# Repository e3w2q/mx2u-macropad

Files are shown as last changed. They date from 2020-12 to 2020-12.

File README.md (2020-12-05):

# MX2U!




Happy Holidays Macro Pad.

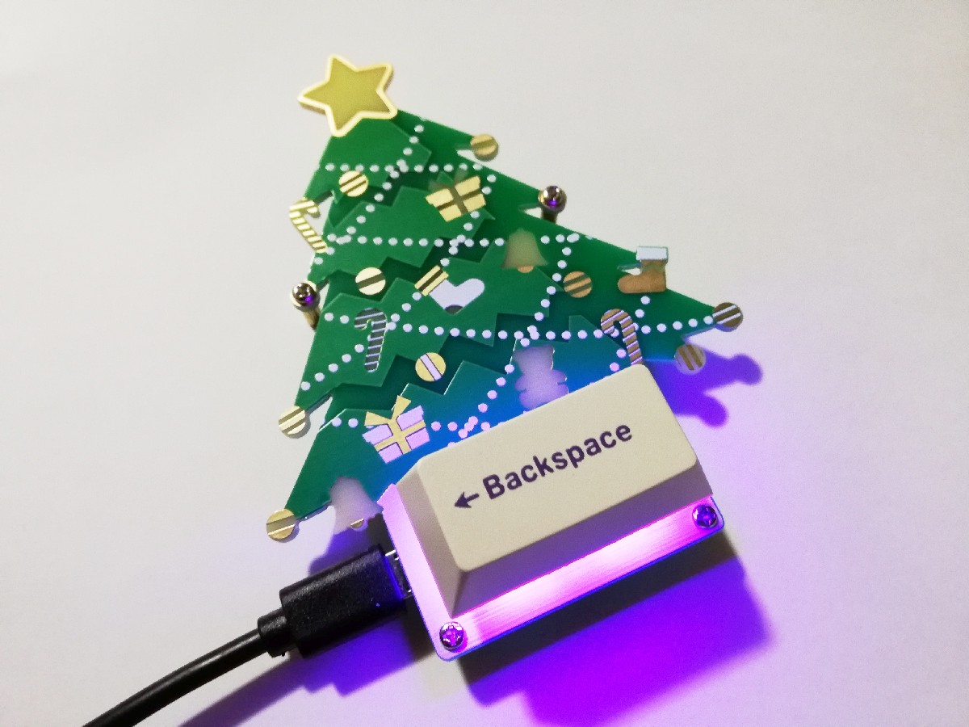
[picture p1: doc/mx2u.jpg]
mx2u


## What is the MX2U! ?

MX2U! is a macro pad for MX switches that can be used for fun at certain times of the year.

You can place a single 2U key or two 1U keys on this macro pad.

Note: When using the 2U key, the backlight goes directly into your eyes!

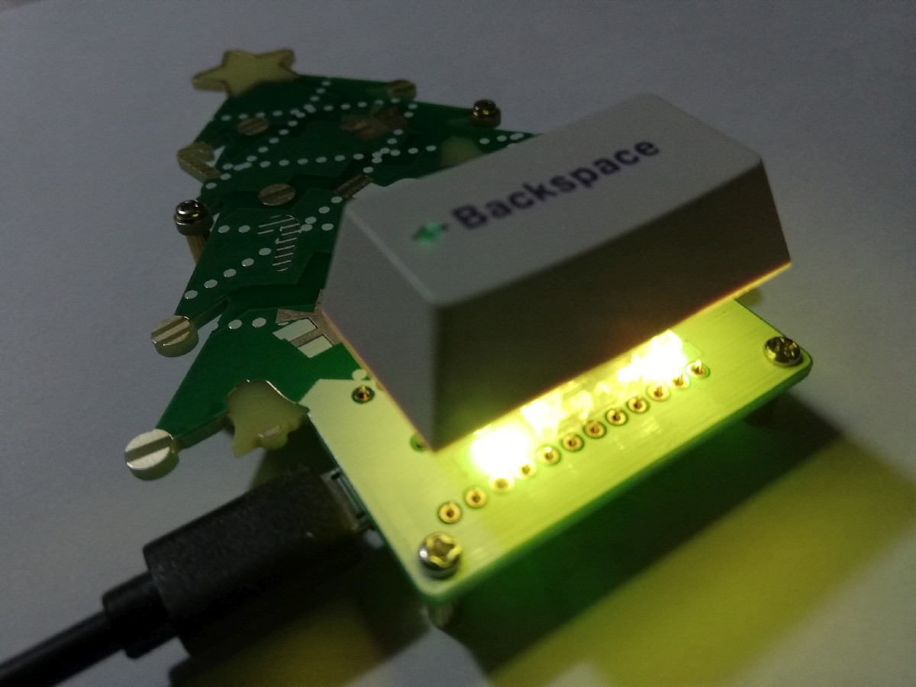
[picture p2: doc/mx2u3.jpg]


## Link

[Hardware data (PCB)](pcb/)

[Firmware](https://github.com/e3w2q/qmk_firmware/tree/e3w2q/keyboards/e3w2q/mx2u)

[PCBの入手方法](doc/pcb_order_guide_jp.md)

[パーツリスト](doc/bom_list_jp.md)

[ビルドガイド](doc/readme_jp.md)

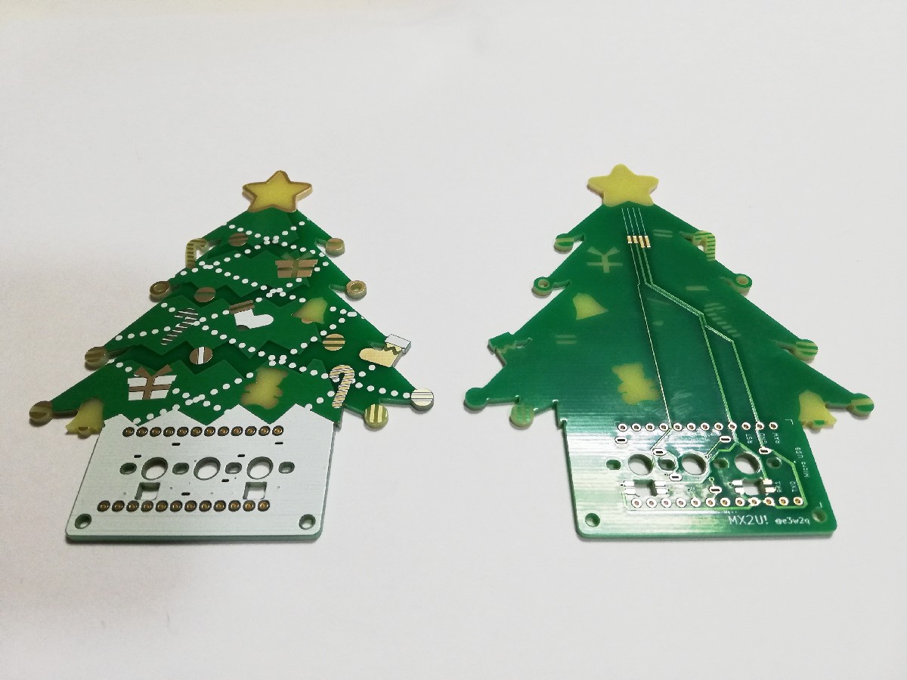
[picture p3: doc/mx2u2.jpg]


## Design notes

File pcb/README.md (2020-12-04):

# MX2U! PCB Data

## Schematic
[Schematic PDF](../doc/ukiha.pdf?raw=true)
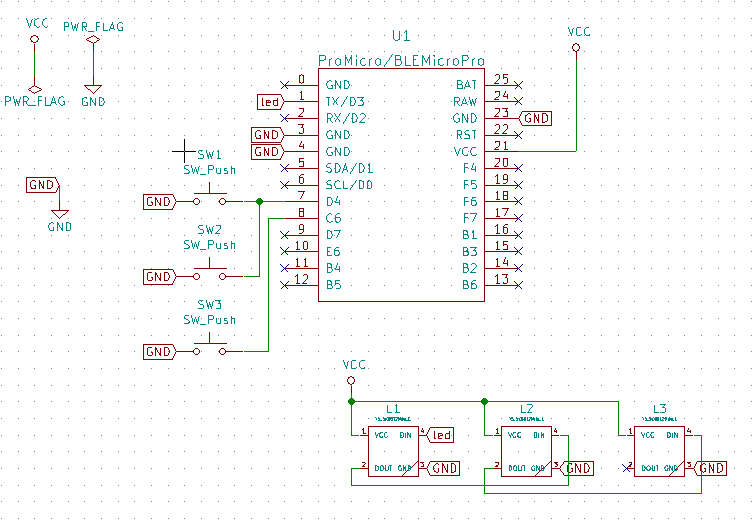
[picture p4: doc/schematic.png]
Schematic


## PCB Layout
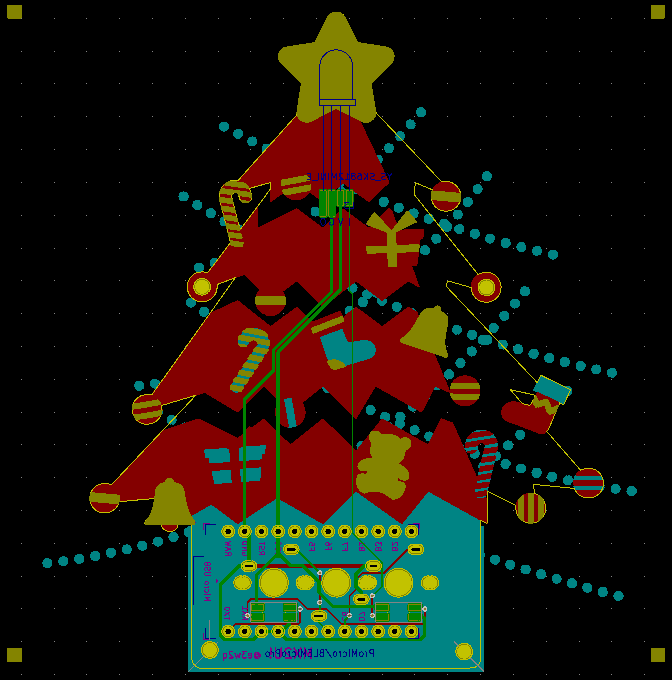
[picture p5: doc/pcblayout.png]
PCB Layout


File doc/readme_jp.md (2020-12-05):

# MX2U! ビルドガイド

<!-- TOC -->

- [MX2U! ビルドガイド](#mx2u-ビルドガイド)
    - [必要なパーツ](#必要なパーツ)
    - [使用する道具、消耗品](#使用する道具消耗品)
    - [ビルドガイド](#ビルドガイド)
        - [Pro Microのもげ防止加工](#pro-microのもげ防止加工)
        - [はんだ付けのイメージトレーニング](#はんだ付けのイメージトレーニング)
        - [キースイッチ部分のLEDの取り付け](#キースイッチ部分のledの取り付け)
        - [ツリー部分のLEDの取り付け](#ツリー部分のledの取り付け)
        - [キースイッチの取り付け](#キースイッチの取り付け)
        - [Pro Microの取り付け](#pro-microの取り付け)
        - [スペーサーの取り付け](#スペーサーの取り付け)
        - [キーキャップの取り付け](#キーキャップの取り付け)
        - [ファームウェアの書き込み](#ファームウェアの書き込み)
        - [光るパターンを変える](#光るパターンを変える)

<!-- /TOC -->

## 必要なパーツ

[MX2U! パーツリスト](bom_list_jp.md)をご覧ください。

## 使用する道具、消耗品

[使用する道具、消耗品](tool_guide_jp.md)におすすめの道具類、注意事項等をまとめましたのでご覧ください。

## ビルドガイド

### Pro Microのもげ防止加工

Pro Microにエポキシ接着剤を盛って、簡単にはもげないようにします。

参考1:[ProMicroのモゲ防止ついでにQMK_Firmwareを書き込む - Qiita](https://qiita.com/hdbx/items/2f3e4ddfcadda2a5578e)
参考2:[もげ予防 - Self-Made Keyboards in Japan](https://scrapbox.io/self-made-kbds-ja/%E3%82%82%E3%81%92%E4%BA%88%E9%98%B2)

エポキシ接着剤の2液を混ぜます。

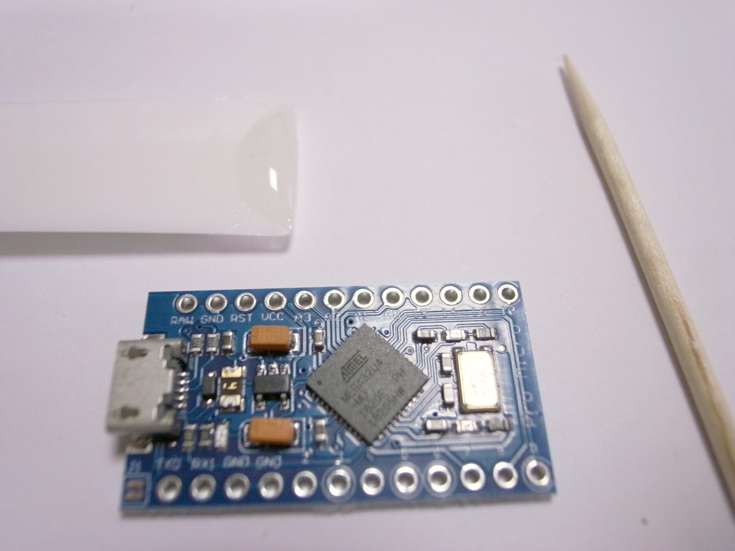
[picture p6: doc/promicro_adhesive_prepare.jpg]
adhesive_prepare


接着剤を付け始める前にMicro USBコネクタを横から見てください。側面に穴が開いています。この穴に接着剤が入ると端子が入らなくなったり、入りにくくなったりします。

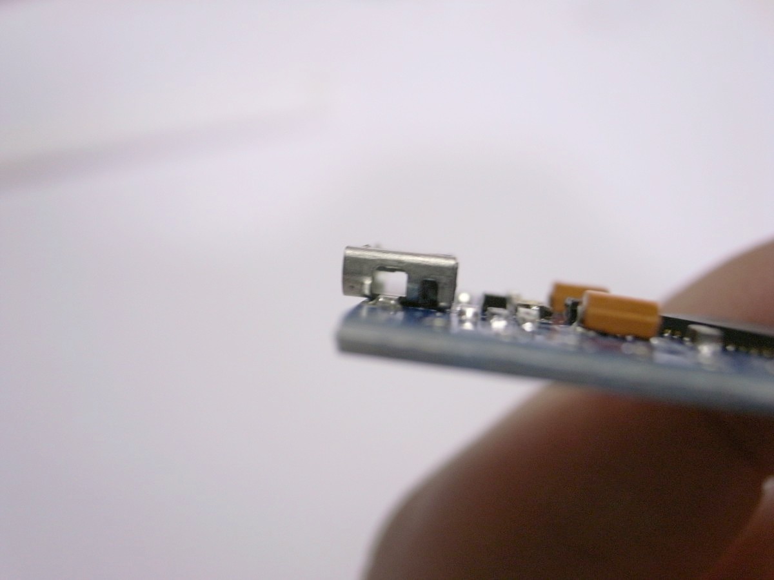
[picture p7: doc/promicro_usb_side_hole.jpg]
usb_side_hole


この穴を避けて、つまようじなどで接着剤を盛っていきます。

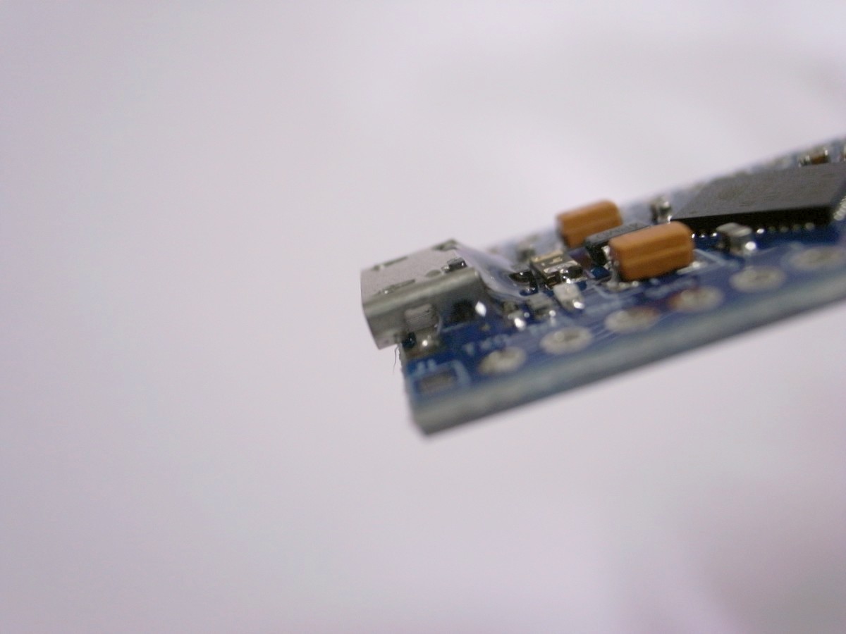
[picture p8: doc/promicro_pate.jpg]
promicro_pate


乾くまで置いておきます。

### はんだ付けのイメージトレーニング

はんだ付けに慣れている方は次の項に進んでください。

全くはんだ付けをしたことがなかったり、数年ぶりにはんだ付けをする場合は、以下の動画が参考になります。

- [はんだ付けの詳細.m2p - YouTube](https://www.youtube.com/watch?v=ZA-ehWjRfYM)

- [チップ抵抗のはんだ付けと、はんだ量の調整（体験用基板を使用） - YouTube](https://www.youtube.com/watch?v=vqKKElJ1vw0)

- [基礎からわかる！自キ入門講座 第8回「自作キーボードのつくりかた #2」 - YouTube](https://www.youtube.com/watch?v=LOC53FeU-QM&t=999)

### キースイッチ部分のLEDの取り付け

**基板裏側**にLEDを取り付けます。

ツリーが描いてある側が基板の表で、反対側が裏です。画像は右側が裏です。

mx2u2

YS-SK6812MINI-Eを取り付けます。向きは写真のように欠けているタブが左下に向くようにして開口部に置き、はんだ付けしてください。

高い温度ではんだ付けを行うと破損の可能性がありますので、温調機能付きはんだごてで270～320度程度に設定してはんだ付けしてください。

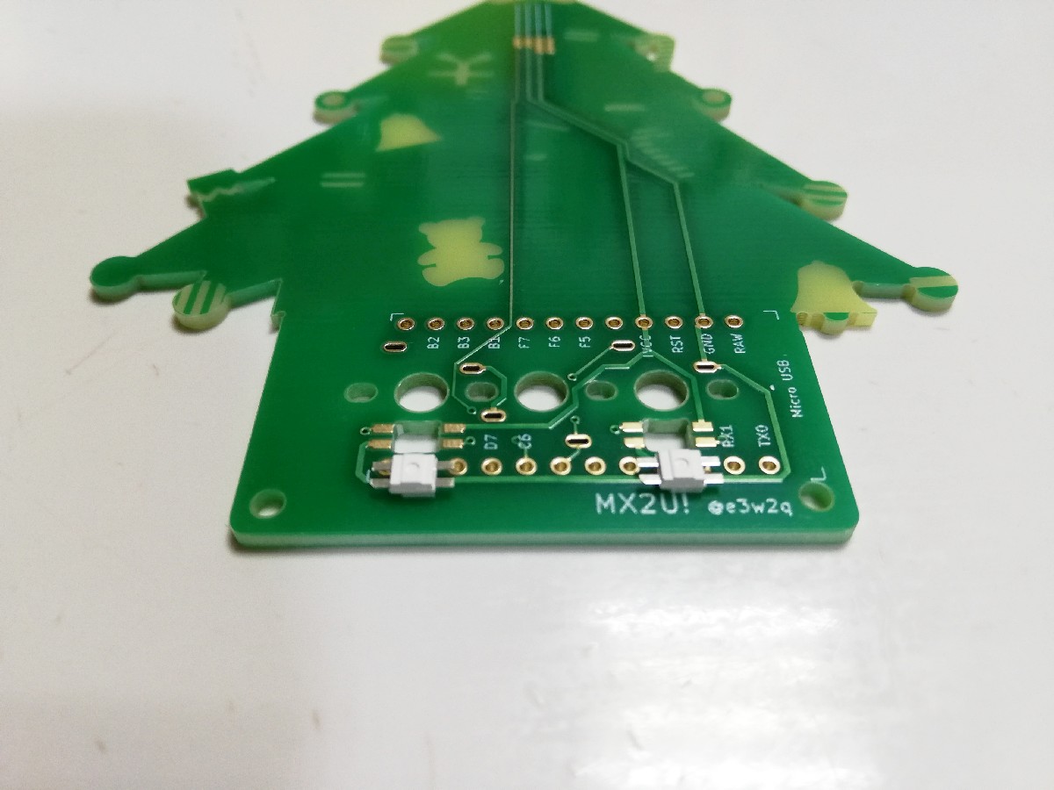
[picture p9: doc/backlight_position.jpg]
backlight_position


### ツリー部分のLEDの取り付け

**この項はまだ未検証です**。

ツリー部分の裏側に、スルーホールタイプのシリアルLED（WS2812）を取り付けます。

裏側から見て左から、Data in(DIN)、電源(VCC)、Ground(GND)、Data out(DOUT)となるように配置します。

はんだ付けしやすいように足をあらかじめ曲げておき、テープ等で固定するとやりやすいです。

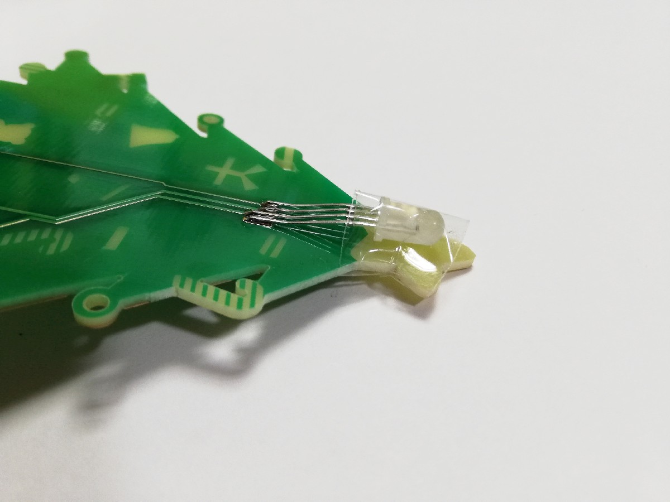
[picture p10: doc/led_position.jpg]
led_position


### キースイッチの取り付け

2Uのキーキャップを使う場合は真ん中に1個、1Uのキーキャップを使う場合は2個、表側から差し込みます。キースイッチの足が曲がっている場合はまっすぐにしてから差し込んでください。

2Uキーキャップを使いたい場合は以下の注意点があります。

- バックライトを光らせるとキースイッチを透過せずにダイレクトに光が出るので、まぶしい
- スタビライザーは使用できない

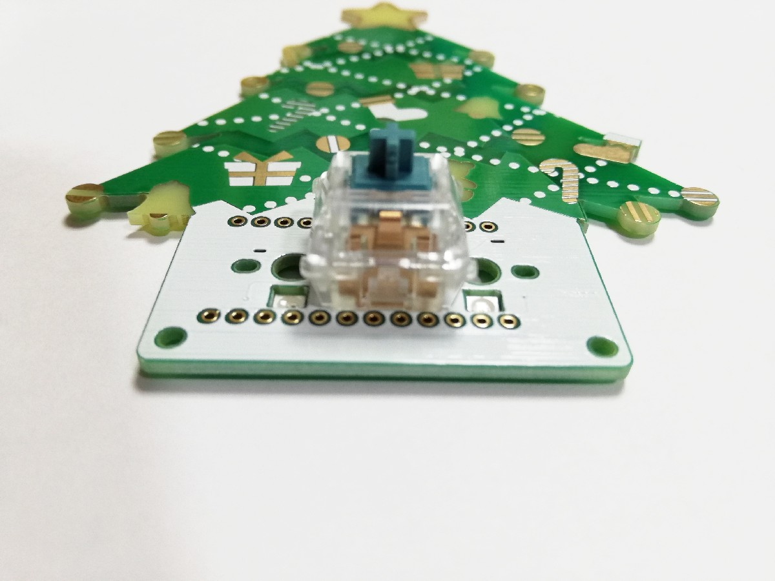
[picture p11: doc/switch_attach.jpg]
switch_attach


裏返します。

スイッチ2個の足がPro Microに干渉しないよう、はみ出した部分をニッパーでカットします。

ハンダ付けします。

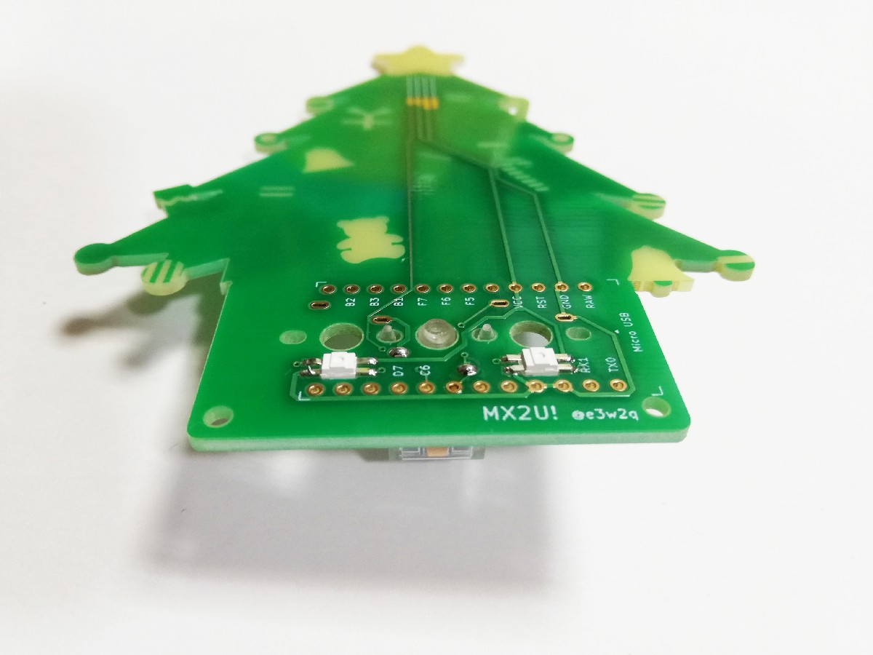
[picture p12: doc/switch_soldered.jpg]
switch_soldered


### Pro Microの取り付け

**基板裏側**のPro Micro設置部分のスルーホールに、コンスルーピンヘッダを根本まで差し込みます。

その際、

- コンスルーピンヘッダの金色の窓が遠い側を基板側とし、金色の窓が近い側をProMicro側とする
- 金色の窓の向きを揃える

ようにしてください。

参考: [Helixベータ ビルドガイド](https://github.com/MakotoKurauchi/helix/blob/master/Doc/buildguide_jp.md#pro-micro)

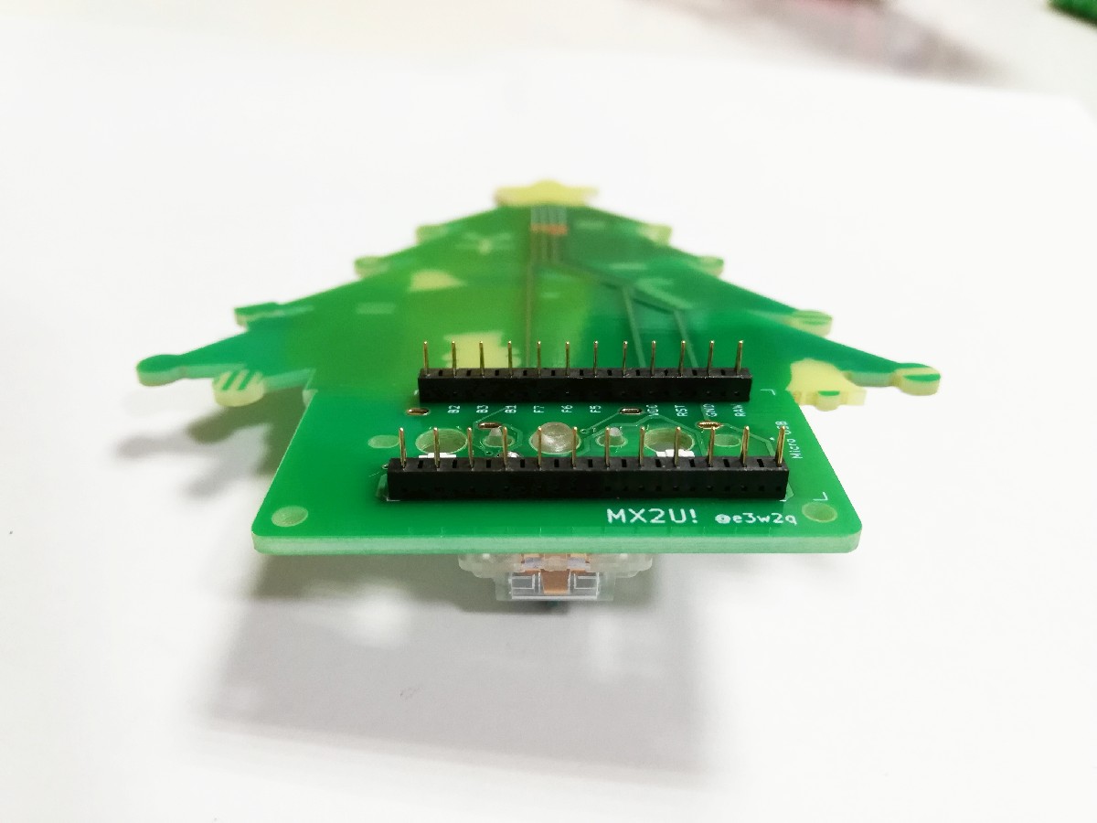
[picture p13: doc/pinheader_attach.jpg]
pinheader_attach


ピンヘッダにPro Microを差し込みます。**Pro Microの裏面（平らなほう）が上になるように、またマイクロUSBが基板端になるように**します。

**向きを間違えるとリカバリーが大変です。表裏、左右をよく確認してください。**

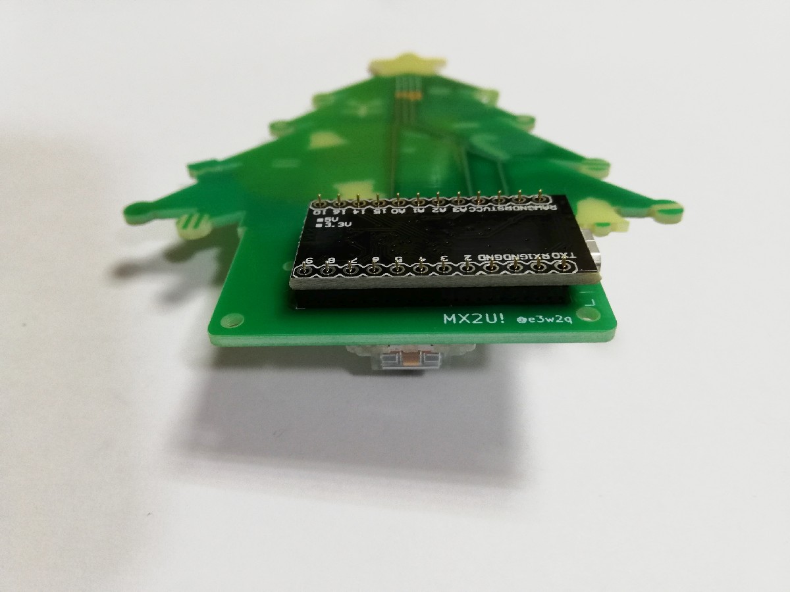
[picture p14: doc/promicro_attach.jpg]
promicro_attach


Pro Microとコンスルーピンヘッダをハンダ付けします。まず四隅をハンダ付けし、横から見てコンスルーピンヘッダとの間に隙間があれば押さえながらハンダを温めて浮かないようにします。そのあと、順番に全てハンダ付けします。

基板とコンスルーピンヘッダは接触しているため、ハンダ付けしません。

### スペーサーの取り付け

基板4箇所の穴に表側からM2ネジをはめ、裏側からスペーサーをねじ込みます。

### キーキャップの取り付け

キースイッチにキーキャップをはめます。

### ファームウェアの書き込み

以下のリンク先を参考にして、QMK Firmwareのビルド環境を用意します。

- Windows
  - [QMKビルド環境の構築(Windows Msys2編)](https://gist.github.com/e3w2q/4bc86e531d1c893d3d13af3e9895a94a)
- macOS
  - [セットアップ - QMK Firmware](https://docs.qmk.fm/#/ja/newbs_getting_started?id=macos)
- Linux
  - [セットアップ - QMK Firmware](https://docs.qmk.fm/#/ja/newbs_getting_started?id=linux)

構築中、

```
qmk setup
```

と入力する代わりに

```
qmk setup e3w2q/qmk_firmware --branch e3w2q
```

と入力してください。

または、`qmk setup`した後に、`C:\Users\USER_NAME\qmk_firmware\keyboards`配下に[https://github.com/e3w2q/qmk_firmware/tree/e3w2q/keyboards/e3w2q](https://github.com/e3w2q/qmk_firmware/tree/e3w2q/keyboards/e3w2q)以下をコピーしてもよいです。

用意されたキーマップを書き込むには以下を実行します。

```
qmk flash -kb e3w2q/mx2u -km default
```

`Detecting USB port, reset your controller now...`と表示されたらPro Microの`GND`と`RST`をピンセットやクリップなどで短絡させると書き込みが始まります。

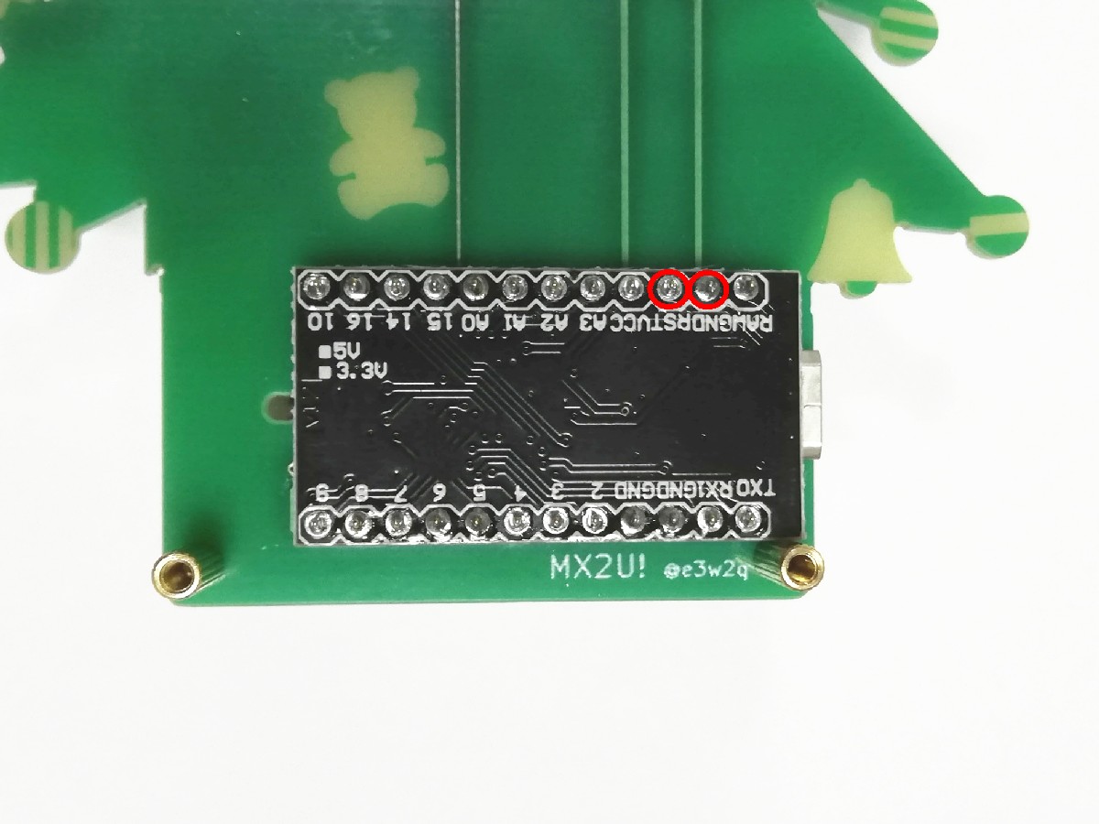
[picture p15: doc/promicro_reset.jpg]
promicro_reset


[QMK Configuratorのテストモード](https://config.qmk.fm/#/test)でキー入力が行えるかテストしてください。

### 光るパターンを変える

デフォルトのキーマップではGNDと以下のピンをピンセットやクリップなどで導通させることで、LEDの設定を変更できます。

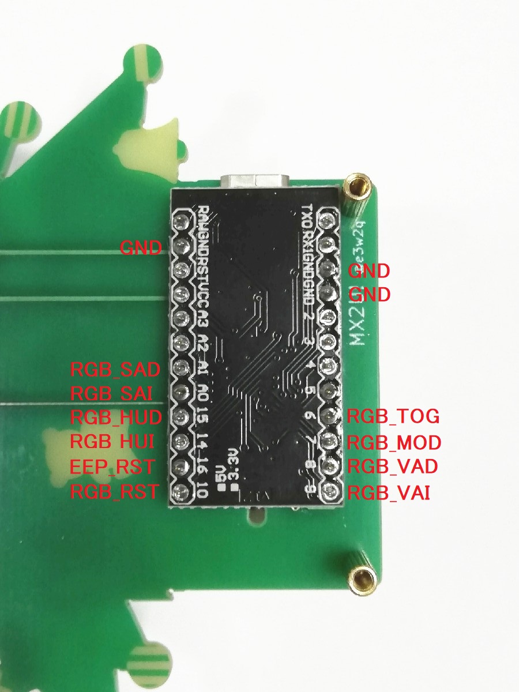
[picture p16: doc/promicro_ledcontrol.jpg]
promicro_ledcontrol


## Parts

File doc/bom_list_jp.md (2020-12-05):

# MX2U! パーツリスト

| 名前 | 数 | 備考 | 調達先の例 | 参考価格 |
| --- | --- | --- | --- | --- |
| MX2U! 基板 | 1枚 | [入手方法はこちら](pcb_order_guide_jp.md) | [Elecrow Online store](https://www.elecrow.com/) | 5枚で$31.70 |
| ★Pro Micro | 1個 | | https://talpkeyboard.stores.jp/items/5b24504ba6e6ee7ec60063e3 | 550円 |
| ★コンスルーピンヘッダ | 2個 | | https://talpkeyboard.stores.jp/items/5e056626d790db16e2889233 | 220円 |
| ★5ピン仕様のMX互換スイッチ または Kailh Mid-Heightスイッチ | 1個または2個 | | https://talpkeyboard.stores.jp/?category_id=59cf8860ed05e668db003f5d | 10個で450円～  |
| ★キーキャップ | 2U1個または1U2個 |  | https://talpkeyboard.stores.jp/items/5f5444c380933970d139e98c | 2個で150円など |
| M2スペーサー | 4個 | 8mm長程度 | https://ja.aliexpress.com/item/4000128244233.html | 50個で$0.74 |
| 鍋頭M2ネジ | 4個 | 3mm～5mm長程度 | https://ja.aliexpress.com/item/32865576659.html | 100個で$0.82 |
| M2ナット | 12個（4×12で使うなら10個） | |  |  |
| YS-SK6812MINI-E | 2個 |  | https://yushakobo.jp/shop/ys-sk6812mini-e/ | 10個で385円 |
| ★WS2812互換のスルーホールタイプのシリアルLED | 1個 | 動作未検証 | スイッチサイエンスのNeoPixel スルーホールLEDはWS2811のため不適合 |  |
| ★Micro USBケーブル | 1本 | 通信ができるもの | ダイソー | 110円 |

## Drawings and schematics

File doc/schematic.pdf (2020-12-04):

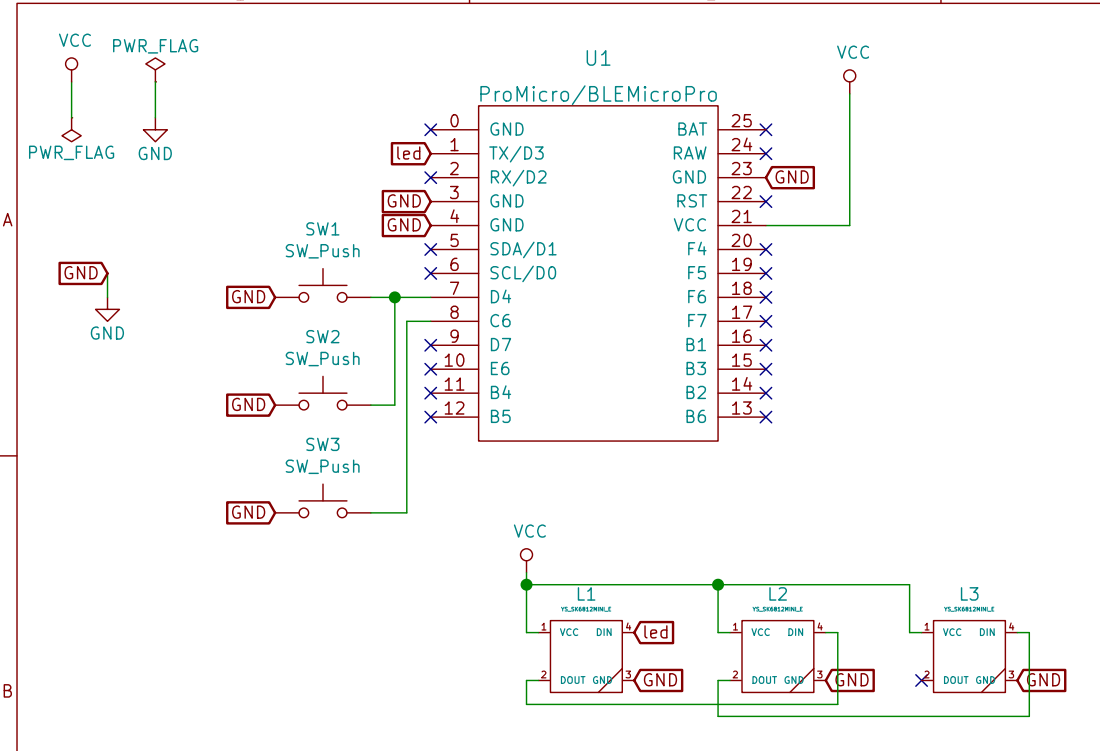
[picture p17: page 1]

led GND GND GND GND GND
SW1 SW_Push SW2 SW_Push SW3 SW_Push

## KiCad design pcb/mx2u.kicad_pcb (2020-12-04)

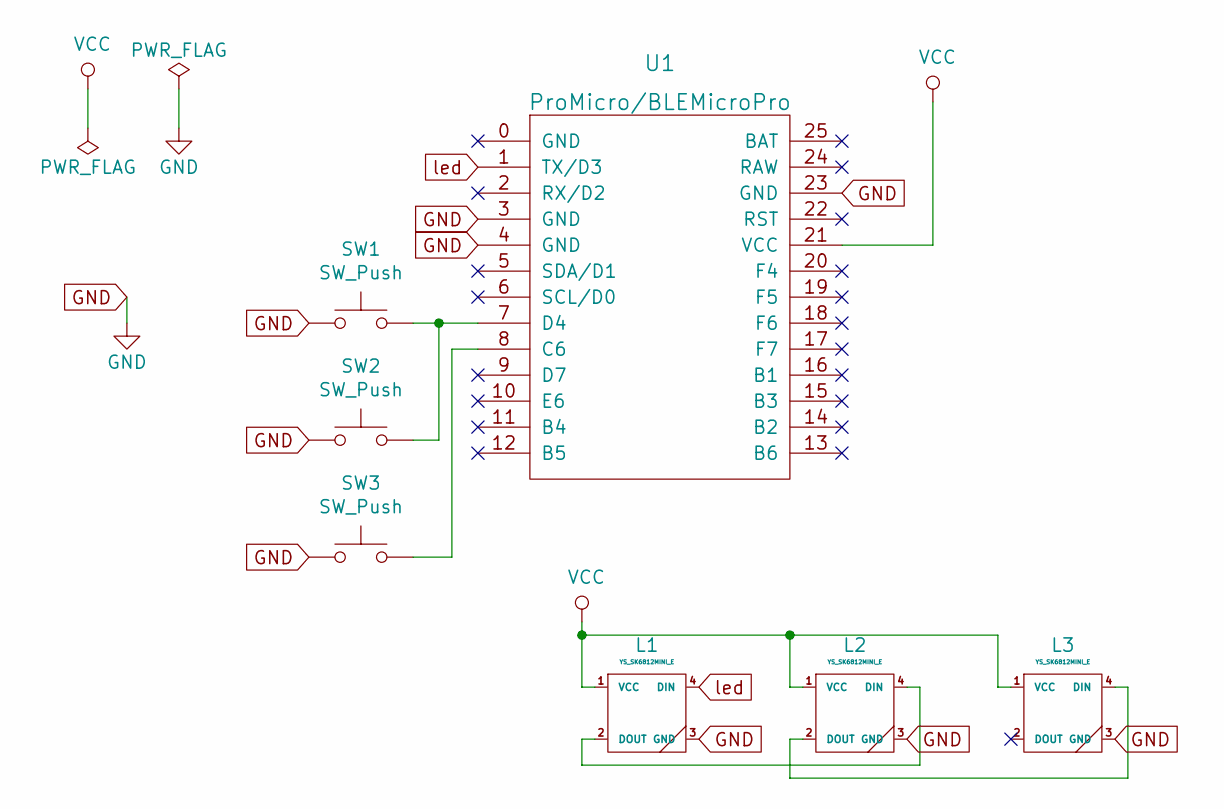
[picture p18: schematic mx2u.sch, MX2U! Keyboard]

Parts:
L1, L2: YS_SK6812MINI_E; YS-SK6812MINI-E
L3: YS_SK6812MINI_E; NeoPixcel_Diffused_5mm_Through_Hole_LED
SW1, SW2, SW3: SW_Push; CherryMX_MidHeight
U1: ProMicro/BLEMicroPro; ArduinoProMicro_ConThrough

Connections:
GND: L1.3 (GND), L2.3 (GND), L3.3 (GND), SW1.1, SW2.1, SW3.1, U1.3 (GND), U1.4 (GND), U1.23 (GND)
unnamed: L1.2 (DOUT), L2.4 (DIN)
unnamed: L2.2 (DOUT), L3.4 (DIN)
unnamed: SW1.2, SW2.2, U1.7 (D4)
unnamed: SW3.2, U1.8 (C6)
VCC: L1.1 (VCC), L2.1 (VCC), L3.1 (VCC), U1.21 (VCC)
led: L1.4 (DIN), U1.1 (TX/D3)

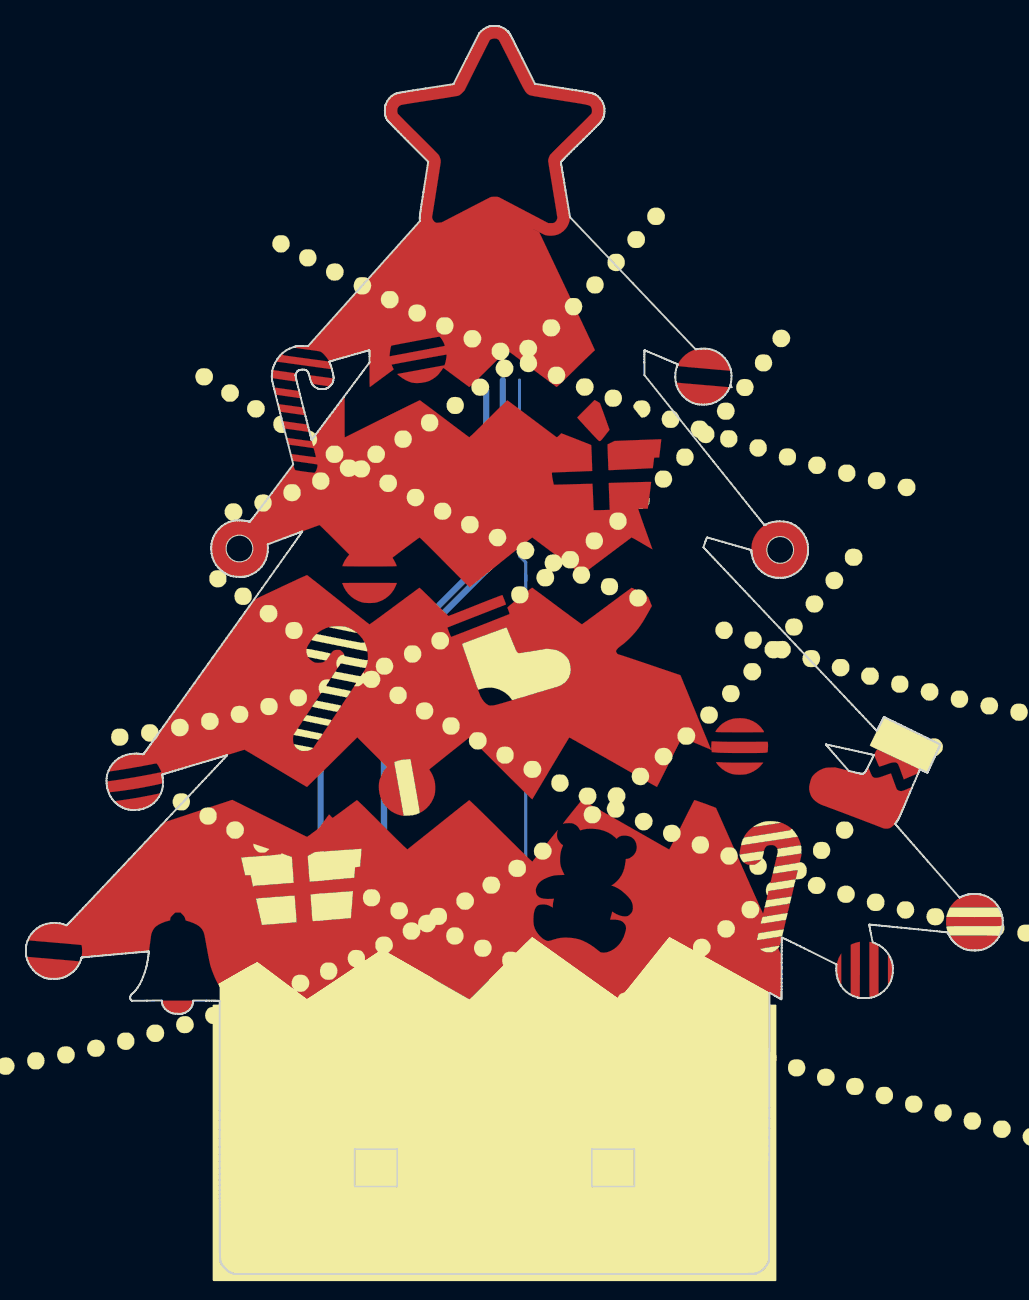
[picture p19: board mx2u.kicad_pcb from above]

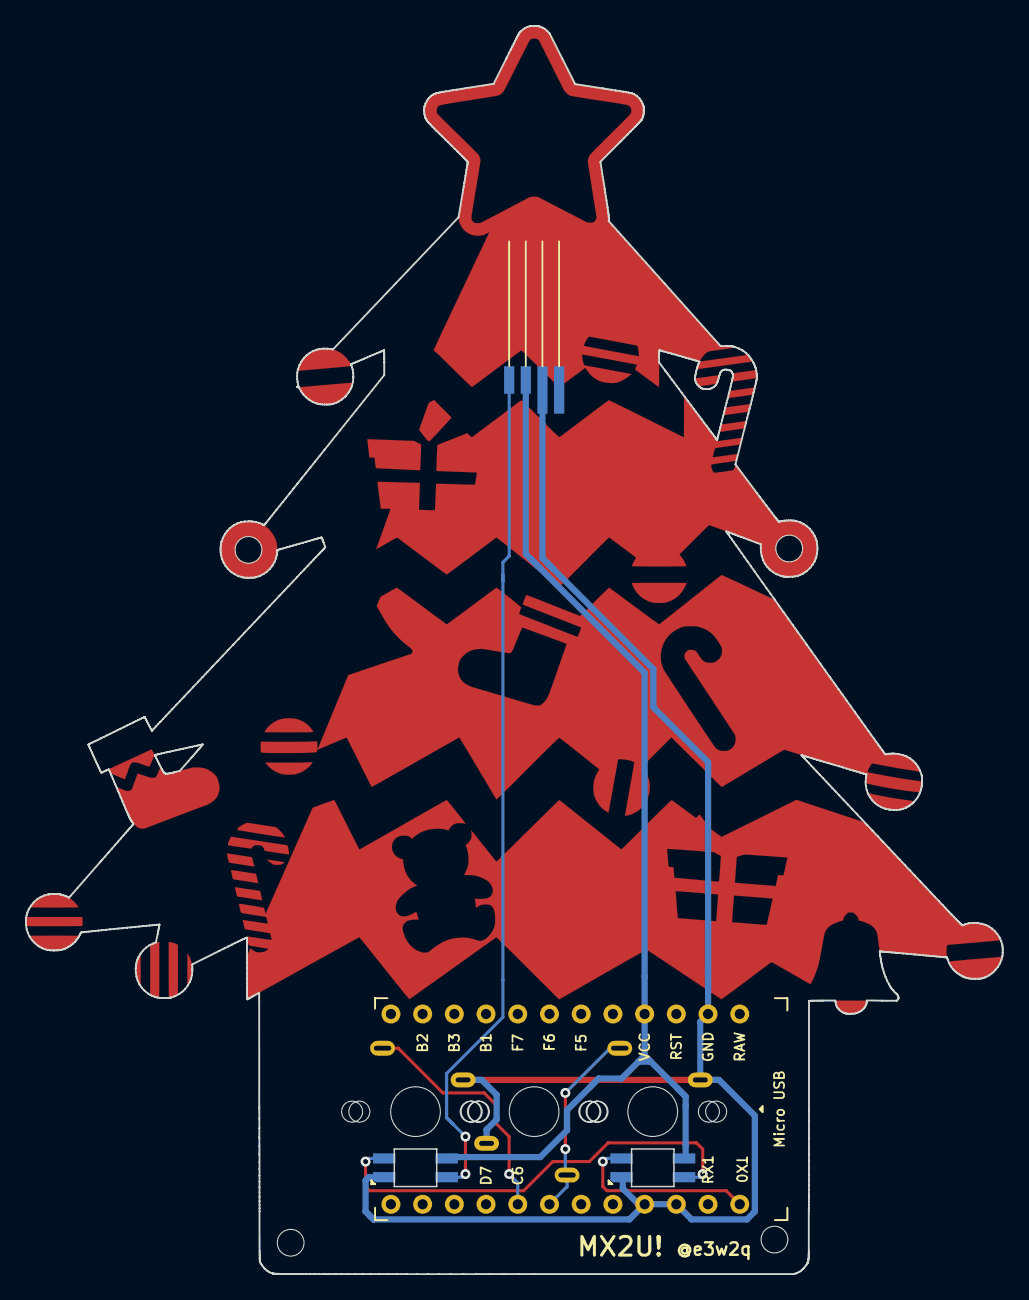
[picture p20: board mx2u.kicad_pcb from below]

Board: 2 copper layers, 78.2 x 100.0 mm, 7 parts (2 on the bottom side), 7 nets.

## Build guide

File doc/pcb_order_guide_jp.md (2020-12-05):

# PCBの入手方法

## ELECROWへ発注する場合

[ELECROW基板製造サービス](https://www.elecrow.com/pcb-manufacturing.html)から注文します。

アップロードするガーバーファイルは以下のものを使ってください。

| 概要 | URL | 寸法 |
| ---- | --- | --- |
| 基板 | https://github.com/e3w2q/mx2u-macropad/blob/main/pcb/mx2u-gerber.zip?raw=true | 100×78mm |

PCB ColorはデフォルトのGreenを選択してください。

Surface FinishはImmersion goldを選択するとメッキが金色になるのでおすすめです。

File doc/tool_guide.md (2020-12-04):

[English](tool_guide.md) / [日本語](tool_guide_jp.md)

# Tools and consumables

## Examples of procured products

This is a list of items that should be procured. The commentary is summarized below.

| Tools, consumables | Product examples | Examples of suppliers | Reference prices |
| ---- | ---- |  ---- |  ---- |
| Soldering iron | White light dial type temperature control soldering iron FX600 | https://www.amazon.co.jp/dp/B006MQD7M4 | 3,900 yen |
| Replacement iron tip | White light tip 2C type T18-C2 | https://www.amazon.co.jp/dp/B004OR7UBM | 478 yen |
| Soldering iron stand | HAKOKO iron stand 633-01 | https://www.amazon.co.jp/dp/B000TGNWCS | 1,680 yen |
| Solder blotter | Sanhayato Solder Shutaro NEO 45W type HSK-300 | https://www.amazon.co.jp/dp/B01FEV2BPG | 4,918 yen |
| Nippers | Engineer Micro Nipper NS-04 | https://www.amazon.co.jp/dp/B000TGJSWG | 1,414 yen |
| Precision screwdriver +0 | Engineer + Precision screwdriver set 6 DM-20 | https://www.amazon.co.jp/dp/B06XXXVPRY | 807 yen |
| Tester | OHM (Ohm Electric) Digital Multi Tester TDB-401 (04-1891) | https://www.amazon.co.jp/dp/B001TVKWWU | 2,543 yen |
| Solder | goot precision printed circuit board solder SD-62 | https://www.amazon.co.jp/dp/B0029LGAMA | 255 yen |
| Equiposhi adhesive two-component mixed type | Cemedine 5 minutes curing epoxy adhesive High Super 5 P15g set CA-188 | https://www.amazon.co.jp/dp/B0036WHO0S | 566 yen |
| Masking tape | Masking tape for 3M Scotch painting 18mm × 18m M40J-18 | https://www.amazon.co.jp/dp/B005JWNJZM | 95 yen |
| Sandpaper | KAKURI Paper File MIX Set, 12 Sheets | https://www.amazon.co.jp/dp/B01ARIEU0A | 436 yen |
| Total | | | 17,092 yen |

## Explanation

### Soldering iron

I do not recommend soldering irons from 100 yen shops.

From [WEBはんだ付け講座 はじめに・・](https://noseseiki.com/kisokouza/01.html)

> Currently, in Japan, soldering irons with no temperature control function are used by the majority of people who solder. These soldering irons have a too high tip temperature of 450-550 ° C. For this reason, most products soldered with this soldering iron will be overheated.

If you don't have much soldering experience or have done it a long time ago, we strongly recommend that you prepare one with temperature control.

### Replacement tip

Since the conical shape attached to the soldering iron from the beginning hits the target and the point, it is difficult for heat to be transmitted, and solder may be placed due to insufficient heating, so replace it with the 2C tip and heat on the surface It is easy to do it if you can.

### Soldering iron stand

Necessary for safely placing the soldering iron.

### Solder blotter or wire

It is good to have it because it is not necessary when soldering fails.

### Nipper

It is used for cutting board / biscuits, cutting diode legs / pin headers.

Nippers are not recommended for 100 yen shops for the following reasons.

- Sharpness is not so good, and it is difficult to cut the diode feet and pin header.
- Since the blade is not a sword, it cannot be cut

### Tester

Necessary for problem isolation when keys cannot be entered.

All you need is a conduction mode.

### Electronic work solder

Leaded type is easy to work with.

Since there are no particularly small parts used for SU120, even a 1mm one can work well, but 0.8mm seems to melt the solder easily.

### Epoxy adhesive two-component mixed type

Used for Pro Micro baldness prevention processing.

### Masking tape

It is used to fix parts when turning the board over by soldering.

## Web page for reference (Japanese)

- [Helix キーボードキットの製作に必要な工具メモ - GitHub](https://gist.github.com/mtei/6957107a676ddfa85bde0ae41f8fa849)
- [自作キーボードを作るために必要なもの - 自作キーボード温泉街の歩き方](https://salicylic-acid3.hatenablog.com/entry/2018/11/24/自作キーボードを作るために必要なもの)
- [自作キーボードの組み立てに使っている工具 | yfuku docs](https://yfuku.com/blog/keyboard/keybord_build_tool/)
- [elephant42 の組み立てかた#工具の準備 · illness072/elephant42](https://github.com/illness072/elephant42/blob/master/docs/build-guide.md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)
- [基礎からわかる！自キ入門講座 第8回「自作キーボードのつくりかた #2」 - YouTube](https://salicylic-acid3.hatenablog.com/entry/2018/11/24/自作キーボードを作るために必要なもの)

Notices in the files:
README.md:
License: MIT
